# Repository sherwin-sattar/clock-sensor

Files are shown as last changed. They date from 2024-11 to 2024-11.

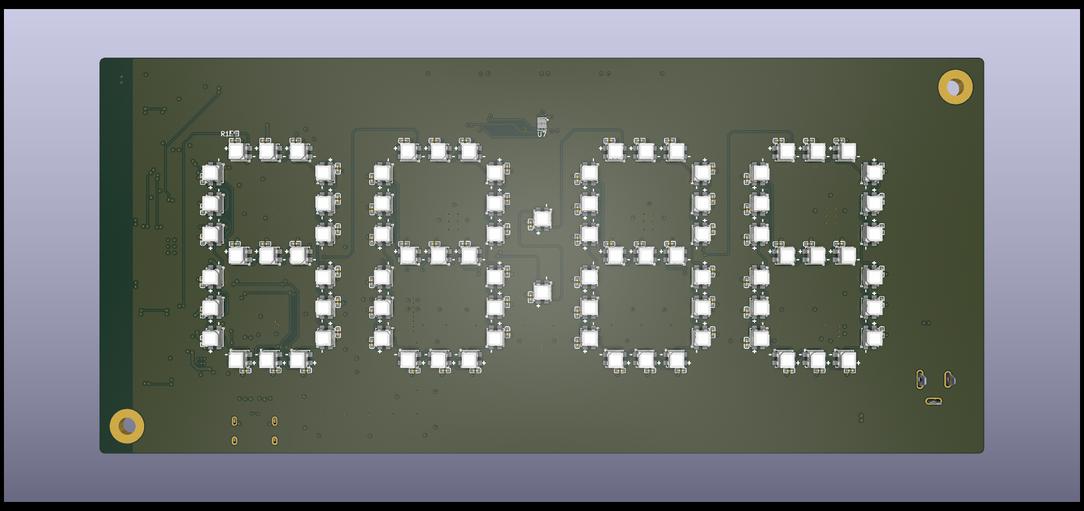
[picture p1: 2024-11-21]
Hardware/3D view/Digital Clock(2).png

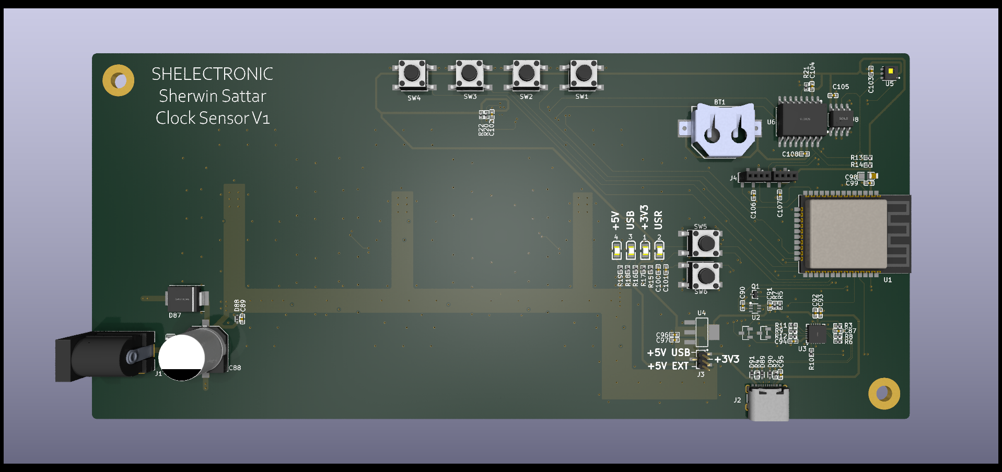
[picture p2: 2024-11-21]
Hardware/3D view/Digital Clock(1).png

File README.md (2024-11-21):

# Clock-Sensor

## User Interface

Web user interface allows seamless control and customization of a clock display, featuring 86 addressable LEDs. Users can adjust and control the clock’s display from anywhere in the world through a secure online connection.
In addition to clock control, the UI also provides real-time monitoring of environmental conditions, including live temperature and humidity readings. Historical data is visualized through easy-to-read graphs, allowing users to track past temperature and humidity trends.

UI-Settings
UI-Data

## 3D views
Digital Clock(2)
Digital Clock(1)

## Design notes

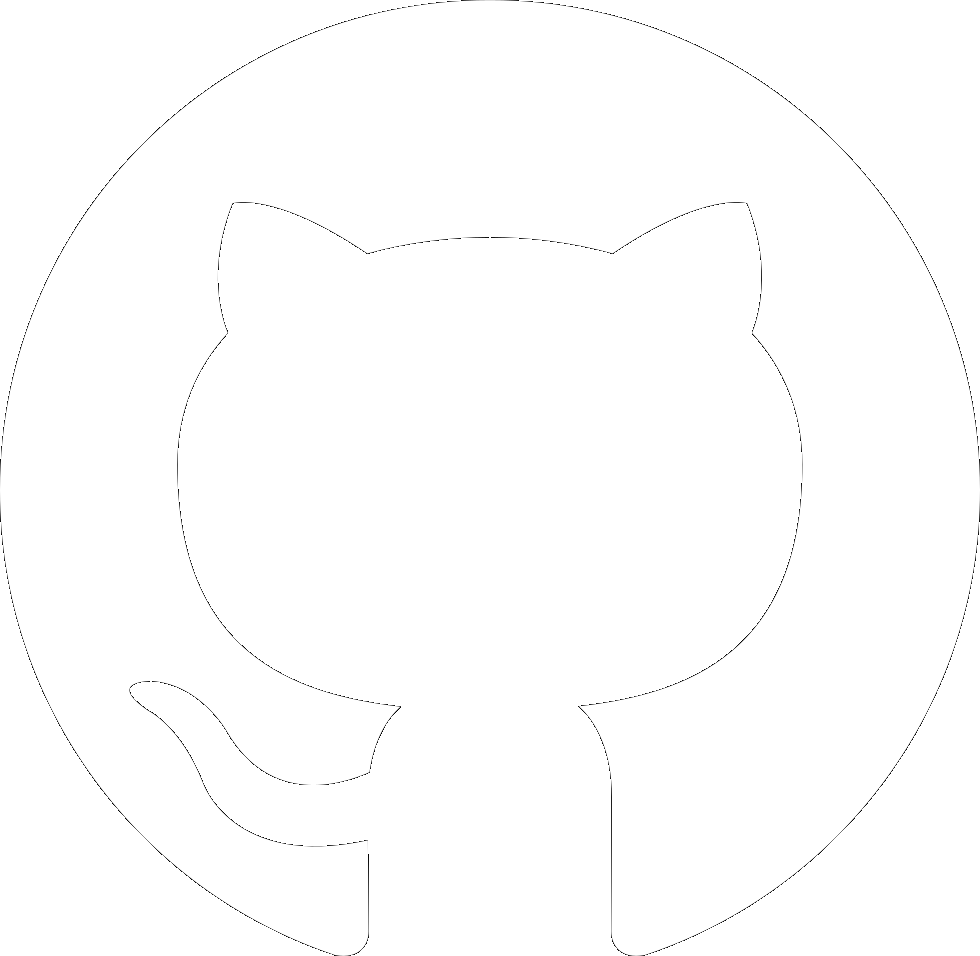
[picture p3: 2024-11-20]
Web_UI/img/git1.png

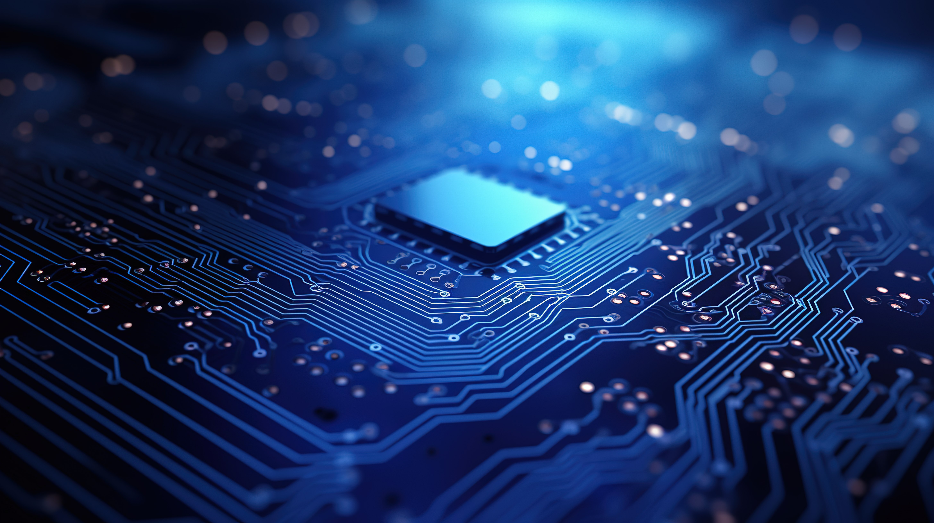
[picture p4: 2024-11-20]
Web_UI/img/home.jpg

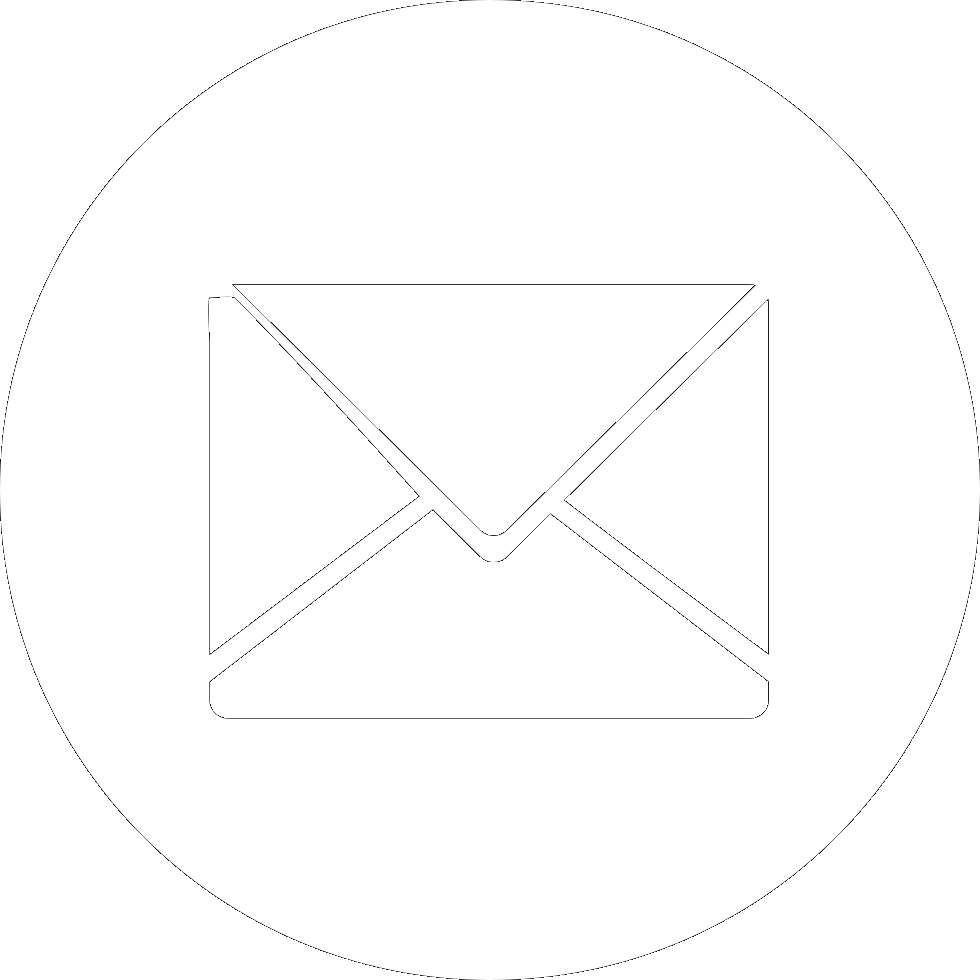
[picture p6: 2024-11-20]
Web_UI/img/mail1.png

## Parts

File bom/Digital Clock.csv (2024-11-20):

Reference | Value | Footprint | LCSC Part | Qty
BT1 | MY-1220-03 | easyeda2kicad:BAT-SMD_MY-1220-03 | C964818 | 1
C1-C87, C89-C91, C93, C94, C99-C108 | 100nF | easyeda2kicad:C0402 | C1525 | 102
C88 | 1000uF | easyeda2kicad:CAP-SMD_BD10.0-L10.3-W10.3-LS11.3-FD | C310843 | 1
C92 | 4.7uF | easyeda2kicad:C0402 | C368809 | 1
C95 | 100n | easyeda2kicad:C0402 | C1525 | 1
C96, C97 | 10uF | easyeda2kicad:C0402 | C315248 | 2
C98 | 22uF | easyeda2kicad:C0805 | C602037 | 1
D1-D86 | WS2812B-MINI | easyeda2kicad:LED-SMD_4P-L3.5-W3.5-TL_WS2812B | C527089 | 86
D87 | SS84 | easyeda2kicad:SMC_L6.9-W5.9-LS7.9-RD | C2943761 | 1
D88 | LESD | easyeda2kicad:SOD-523_L1.2-W0.8-LS1.6-BI | C383211 | 1
D89-D91 | ~ | easyeda2kicad:SOD-523_L1.2-W0.8-LS1.6-BI | C383211 | 3
F1 | SMD1206-600-6V | easyeda2kicad:F1206 | C2760310 | 1
H1, H2 | MountingHole | MountingHole:MountingHole_3.7mm_Pad_TopBottom |  | 2
J1 | DC-005H-D025 | easyeda2kicad:DC-IN-TH_G-SWITCH_DC-005H-D025 | C5353839 | 1
J2 | TYPE-C 16PIN 2MD(073) | easyeda2kicad:USB-C-SMD_TYPE-C-6PIN-2MD-073 | C2765186 | 1
J3 | X1311WVS-03J-C40D42R2 | easyeda2kicad:HDR-SMD_3P-P1.27-V-M-LS4.2_X1311WVS-03J-C40D42R2 | C5243526 | 1
J4, J5 | X1311FVS-04-C43D35R2 | easyeda2kicad:HDR-SMD_4P-P1.27-V-F-LS4.5_R2 | C2881513 | 2
LED1, LED3, LED4 | 0805G (Green) | easyeda2kicad:LED0805-R-RD | C2297 | 3
LED2 | FC-2012HRK (RED) | easyeda2kicad:LED0805-R-RD | C84256 | 1
Q1 | 2N7002T-7-F | easyeda2kicad:SOT-523-3_L1.6-W0.8-P1.00-LS1.6-BR | C139445 | 1
Q2, Q3 | SS8050-G | easyeda2kicad:SOT-23-3_L2.9-W1.3-P1.90-LS2.4-BR | C164886 | 2
R1 | 0402WGF4700TCE | easyeda2kicad:R0402 | C25117 | 1
R2, R4, R16 | 5.1k | easyeda2kicad:R0402 | C25905 | 3
R3, R10, R11, R20, R21 | 0 | easyeda2kicad:R0402 | C17168 | 5
R5 | 1k | easyeda2kicad:R0402 | C11702 | 1
R6, R8 | 27R | easyeda2kicad:R0402 | C138021 | 2
R7, R9, R12, R15, R18, R19, R22 | 10k | easyeda2kicad:R0402 | C25744 | 7
R13, R14 | 2.2k | easyeda2kicad:R0402 | C25879 | 2
R17 | 560 | easyeda2kicad:R0402 | C25126 | 1
SW1-SW6 | PTS645SH50SMTR92LFS | easyeda2kicad:KEY-SMD_4P-L6.0-W6.0-P4.50-LS9.0 | C221869 | 6
U1 | ESP32-WROOM-32E(8MB) | easyeda2kicad:WIFI-SMD_ESP32-WROOM-32E | C701342 | 1
U2 | SN74LVC1T45DCKR | easyeda2kicad:SC-70-6_L2.2-W1.3-P0.65-LS2.2-BR | C9382 | 1
U3 | FT231XQ-R | easyeda2kicad:QFN-20_L4.0-W4.0-P0.50-BL-EP2.2 | C132159 | 1
U4 | AMS1117-3.3_C347222 | easyeda2kicad:SOT-223-4_L6.5-W3.5-P2.30-LS7.0-BR | C347222 | 1
U5 | HDC1080DMBR | easyeda2kicad:SENSOR-SMD_HDC1080DMBR | C82227 | 1
U6 | DS3231SN# | easyeda2kicad:SOIC-16_L10.3-W7.5-P1.27-LS10.3-BL | C9866 | 1
U7 | OPT3001DNPR | easyeda2kicad:USON6_L2.1-W2.1-P0.65-BL-EP | C90462 | 1
U8 | 24LC256T-I/SN SOP-8 | easyeda2kicad:SOIC-8_L4.9-W3.9-P1.27-LS6.0-BL | C5458 | 1

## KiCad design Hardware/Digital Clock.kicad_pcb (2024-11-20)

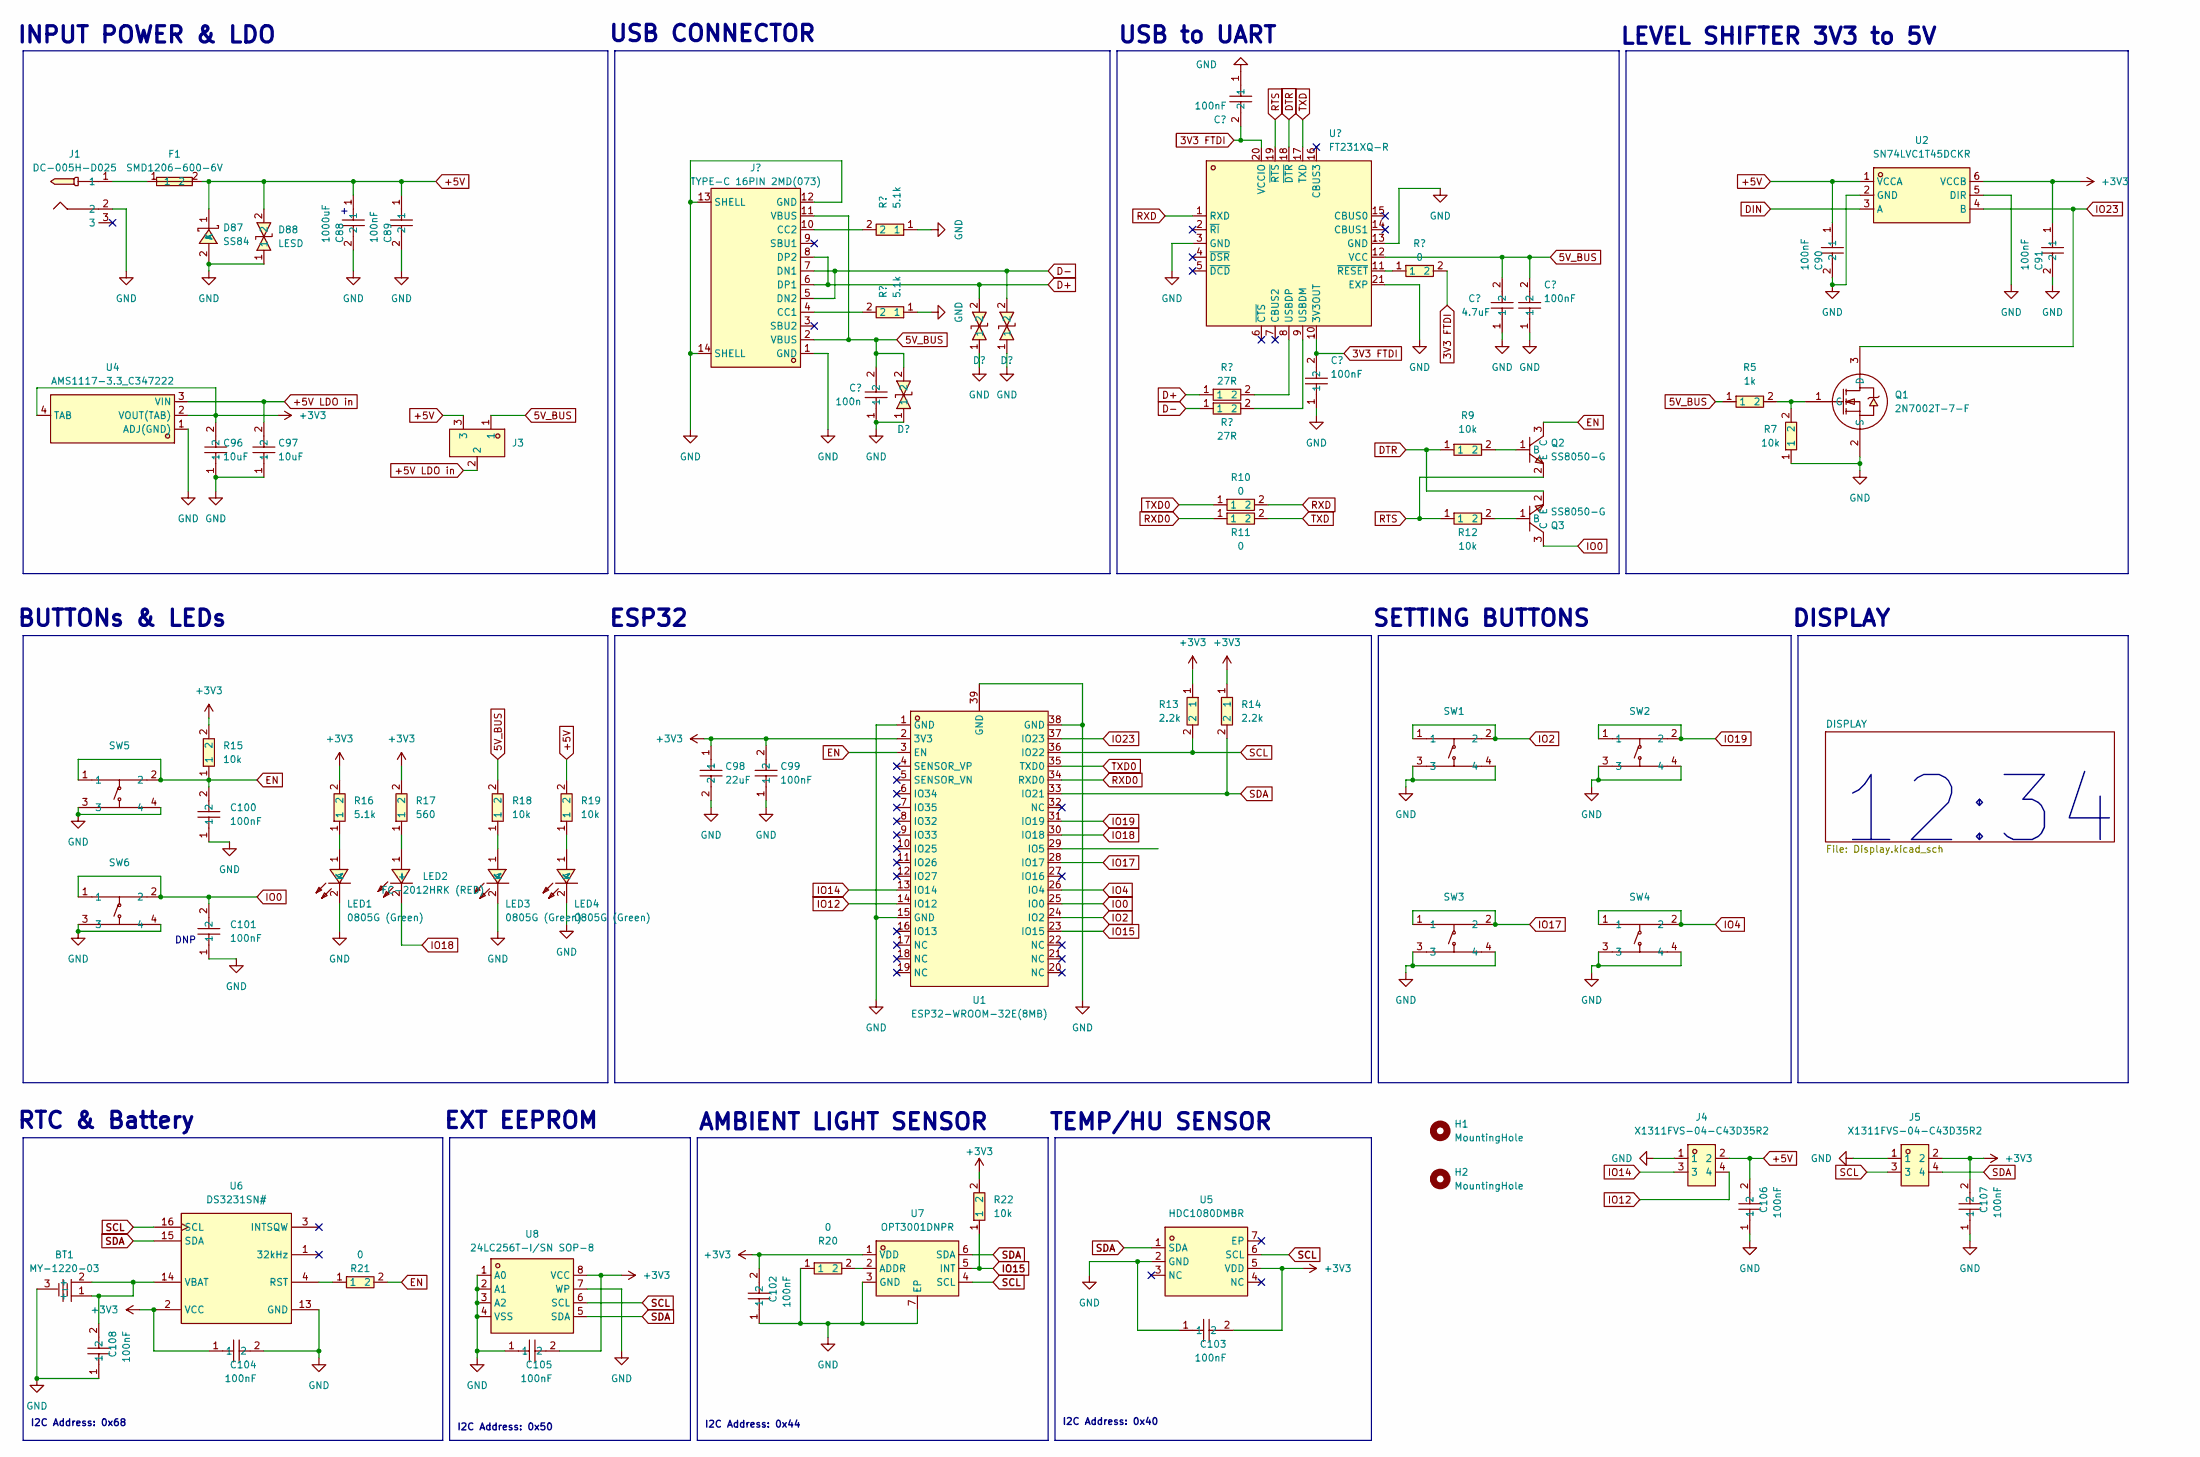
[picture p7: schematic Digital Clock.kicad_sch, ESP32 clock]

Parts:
BT1: MY-1220-03; BAT-SMD_MY-1220-03; LCSC Part C964818
C87, C89, C90, C91, C93, C94, C99, C100, C101, C102, C103, C104, C105, C106, C107, C108: 100nF; C0402; LCSC Part C1525
C88: 1000uF; CAP-SMD_BD10.0-L10.3-W10.3-LS11.3-FD; LCSC Part C310843
C92: 4.7uF; C0402; LCSC Part C368809
C95: 100n; C0402; LCSC Part C1525
C96, C97: 10uF; C0402; LCSC Part C315248
C98: 22uF; C0805; LCSC Part C602037
D87: SS84; SMC_L6.9-W5.9-LS7.9-RD; LCSC Part C2943761
D88: LESD; SOD-523_L1.2-W0.8-LS1.6-BI; LCSC Part C383211
D89, D90, D91: SOD-523_L1.2-W0.8-LS1.6-BI; LCSC Part C383211
F1: SMD1206-600-6V; F1206; LCSC Part C2760310
H1, H2: MountingHole; MountingHole_3.7mm_Pad_TopBottom
J1: DC-005H-D025; DC-IN-TH_G-SWITCH_DC-005H-D025; LCSC Part C5353839
J2: TYPE-C 16PIN 2MD(073); USB-C-SMD_TYPE-C-6PIN-2MD-073; LCSC Part C2765186
J3: X1311WVS-03J-C40D42R2; HDR-SMD_3P-P1.27-V-M-LS4.2_X1311WVS-03J-C40D42R2; LCSC Part C5243526
J4, J5: X1311FVS-04-C43D35R2; HDR-SMD_4P-P1.27-V-F-LS4.5_R2; LCSC Part C2881513
LED1, LED3, LED4: 0805G (Green); LED0805-R-RD; LCSC Part C2297
LED2: FC-2012HRK (RED); LED0805-R-RD; LCSC Part C84256
Q1: 2N7002T-7-F; SOT-523-3_L1.6-W0.8-P1.00-LS1.6-BR; LCSC Part C139445
Q2, Q3: SS8050-G; SOT-23-3_L2.9-W1.3-P1.90-LS2.4-BR; LCSC Part C164886
R2, R4, R16: 5.1k; R0402; LCSC Part C25905
R3, R10, R11, R20, R21: 0; R0402; LCSC Part C17168
R5: 1k; R0402; LCSC Part C11702
R6, R8: 27R; R0402; LCSC Part C138021
R7, R9, R12, R15, R18, R19, R22: 10k; R0402; LCSC Part C25744
R13, R14: 2.2k; R0402; LCSC Part C25879
R17: 560; R0402; LCSC Part C25126
SW1, SW2, SW3, SW4, SW5, SW6: PTS645SH50SMTR92LFS; KEY-SMD_4P-L6.0-W6.0-P4.50-LS9.0; LCSC Part C221869
U1: ESP32-WROOM-32E(8MB); WIFI-SMD_ESP32-WROOM-32E; LCSC Part C701342
U2: SN74LVC1T45DCKR; SC-70-6_L2.2-W1.3-P0.65-LS2.2-BR; LCSC Part C9382
U3: FT231XQ-R; QFN-20_L4.0-W4.0-P0.50-BL-EP2.2; LCSC Part C132159
U4: AMS1117-3.3_C347222; SOT-223-4_L6.5-W3.5-P2.30-LS7.0-BR; LCSC Part C347222
U5: HDC1080DMBR; SENSOR-SMD_HDC1080DMBR; LCSC Part C82227
U6: DS3231SN#; SOIC-16_L10.3-W7.5-P1.27-LS10.3-BL; LCSC Part C9866
U7: OPT3001DNPR; USON6_L2.1-W2.1-P0.65-BL-EP; LCSC Part C90462
U8: 24LC256T-I/SN SOP-8; SOIC-8_L4.9-W3.9-P1.27-LS6.0-BL; LCSC Part C5458

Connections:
3V3 FTDI: C87.2, C94.2, R3.2, U3.10 (3V3OUT), U3.20 (VCCIO)
5V_BUS: C92.2, C93.2, C95.2, D91.2, J2.2 (VBUS), J2.11 (VBUS), J3.1, R5.1, R18.2, U3.12 (VCC)
+3V3: C91.1, C96.2, C98.1, C99.2, C102.2, C103.2, C104.1, C105.2, C107.2, J5.2, R13.1, R14.1, R15.2, R16.2, R17.2, R22.2, U1.2 (3V3), U2.6 (VCCB), U4.2 (VOUT(TAB)), U4.4 (TAB), U5.5 (VDD), U6.2 (VCC), U7.1 (VDD), U8.8 (VCC)
+5V: C88.1, C89.1, C90.1, C106.2, D87.1 (K), D88.2, F1.2, J3.3, J4.2, R19.2, U2.1 (VCCA); also elsewhere on the board
+5V LDO in: C97.2, J3.2, U4.3 (VIN)
D+: D89.2, J2.6 (DP1), J2.8 (DP2), R6.1
D-: D90.2, J2.5 (DN2), J2.7 (DN1), R8.1
DIN: U2.3 (A); also elsewhere on the board
DTR: Q3.2 (E), R9.1, U3.18 (~DTR)
EN: C100.2, Q2.3 (C), R15.1, R21.2, SW5.1, SW5.2, U1.3 (EN)
GND: BT1.3 (-), C87.1, C88.2, C89.2, C90.2, C91.2, C92.1, C93.1, C94.1, C95.1, C96.1, C97.1, C98.2, C99.1, C100.1, C101.1, C102.1, C103.1, C104.2, C105.1, C106.1, C107.1, C108.1, D87.2 (A), D88.1, D89.1, D90.1, D91.1, J1.2, J2.1 (GND), J2.12 (GND), J2.13 (SHELL), J2.14 (SHELL), J4.1, J5.1, LED1.2 (K), LED3.2 (K), LED4.2 (K), Q1.2 (S), R2.1, R4.1, R7.1, R20.1, SW1.3, SW1.4, SW2.3, SW2.4, SW3.3, SW3.4, SW4.3, SW4.4, SW5.3, SW5.4, SW6.3, SW6.4, U1.1 (GND), U1.15 (GND), U1.38 (GND), U1.39 (GND), U2.2 (GND), U2.5 (DIR), U3.3 (GND), U3.13 (GND), U3.21 (EXP), U4.1 (ADJ(GND)), U5.2 (GND), U6.13 (GND), U7.3 (GND), U7.7 (EP), U8.1 (A0), U8.2 (A1), U8.3 (A2), U8.4 (VSS), U8.7 (WP); also elsewhere on the board
IO0: C101.2, Q3.3 (C), SW6.1, SW6.2, U1.25 (IO0)
IO2: SW1.1, SW1.2, U1.24 (IO2)
IO4: SW4.1, SW4.2, U1.26 (IO4)
IO12: J4.4, U1.14 (IO12)
IO14: J4.3, U1.13 (IO14)
IO15: R22.1, U1.23 (IO15), U7.5 (INT)
IO17: SW3.1, SW3.2, U1.28 (IO17)
IO18: LED2.2 (-), U1.30 (IO18); also elsewhere on the board
IO19: SW2.1, SW2.2, U1.31 (IO19)
IO23: Q1.3 (D), U1.37 (IO23), U2.4 (B)
unnamed: F1.1, J1.1
unnamed: J2.4 (CC1), R4.2
unnamed: J2.10 (CC2), R2.2
unnamed 102: LED1.1 (A), R16.1; also elsewhere on the board
unnamed 103: LED2.1 (+), R17.1; also elsewhere on the board
unnamed 104: LED3.1 (A), R18.1; also elsewhere on the board
unnamed 105: LED4.1 (A), R19.1; also elsewhere on the board
unnamed: Q1.1 (G), R5.2, R7.2
unnamed: Q2.1 (B), R9.2
unnamed: Q3.1 (B), R12.2
unnamed: R8.2, U3.9 (USBDM)
unnamed: R6.2, U3.8 (USBDP)
unnamed: R3.1, U3.11 (~RESET)
unnamed: R21.1, U6.4 (RST)
unnamed: BT1.1 (+), BT1.2 (+), C108.2, U6.14 (VBAT)
unnamed: R20.2, U7.2 (ADDR)
RTS: Q2.2 (E), R12.1, U3.19 (~RTS)
RXD: R10.2, U3.1 (RXD)
RXD0: R11.1, U1.34 (RXD0)
SCL: J5.3, R13.2, U1.36 (IO22), U5.6 (SCL), U6.16 (SCL), U7.4 (SCL), U8.6 (SCL)
SDA: J5.4, R14.2, U1.33 (IO21), U5.1 (SDA), U6.15 (SDA), U7.6 (SDA), U8.5 (SDA)
TXD: R11.2, U3.17 (TXD)
TXD0: R10.1, U1.35 (TXD0)

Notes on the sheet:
I2C Address: 0x44
INPUT POWER & LDO
USB CONNECTOR
BUTTONs & LEDs
USB to UART
ESP32
RTC & Battery
I2C Address: 0x68
EXT EEPROM
AMBIENT LIGHT SENSOR
I2C Address: 0x50
I2C Address: 0x40
DNP
TEMP/HU SENSOR
12:34
LEVEL SHIFTER 3V3 to 5V
SETTING BUTTONS
DISPLAY

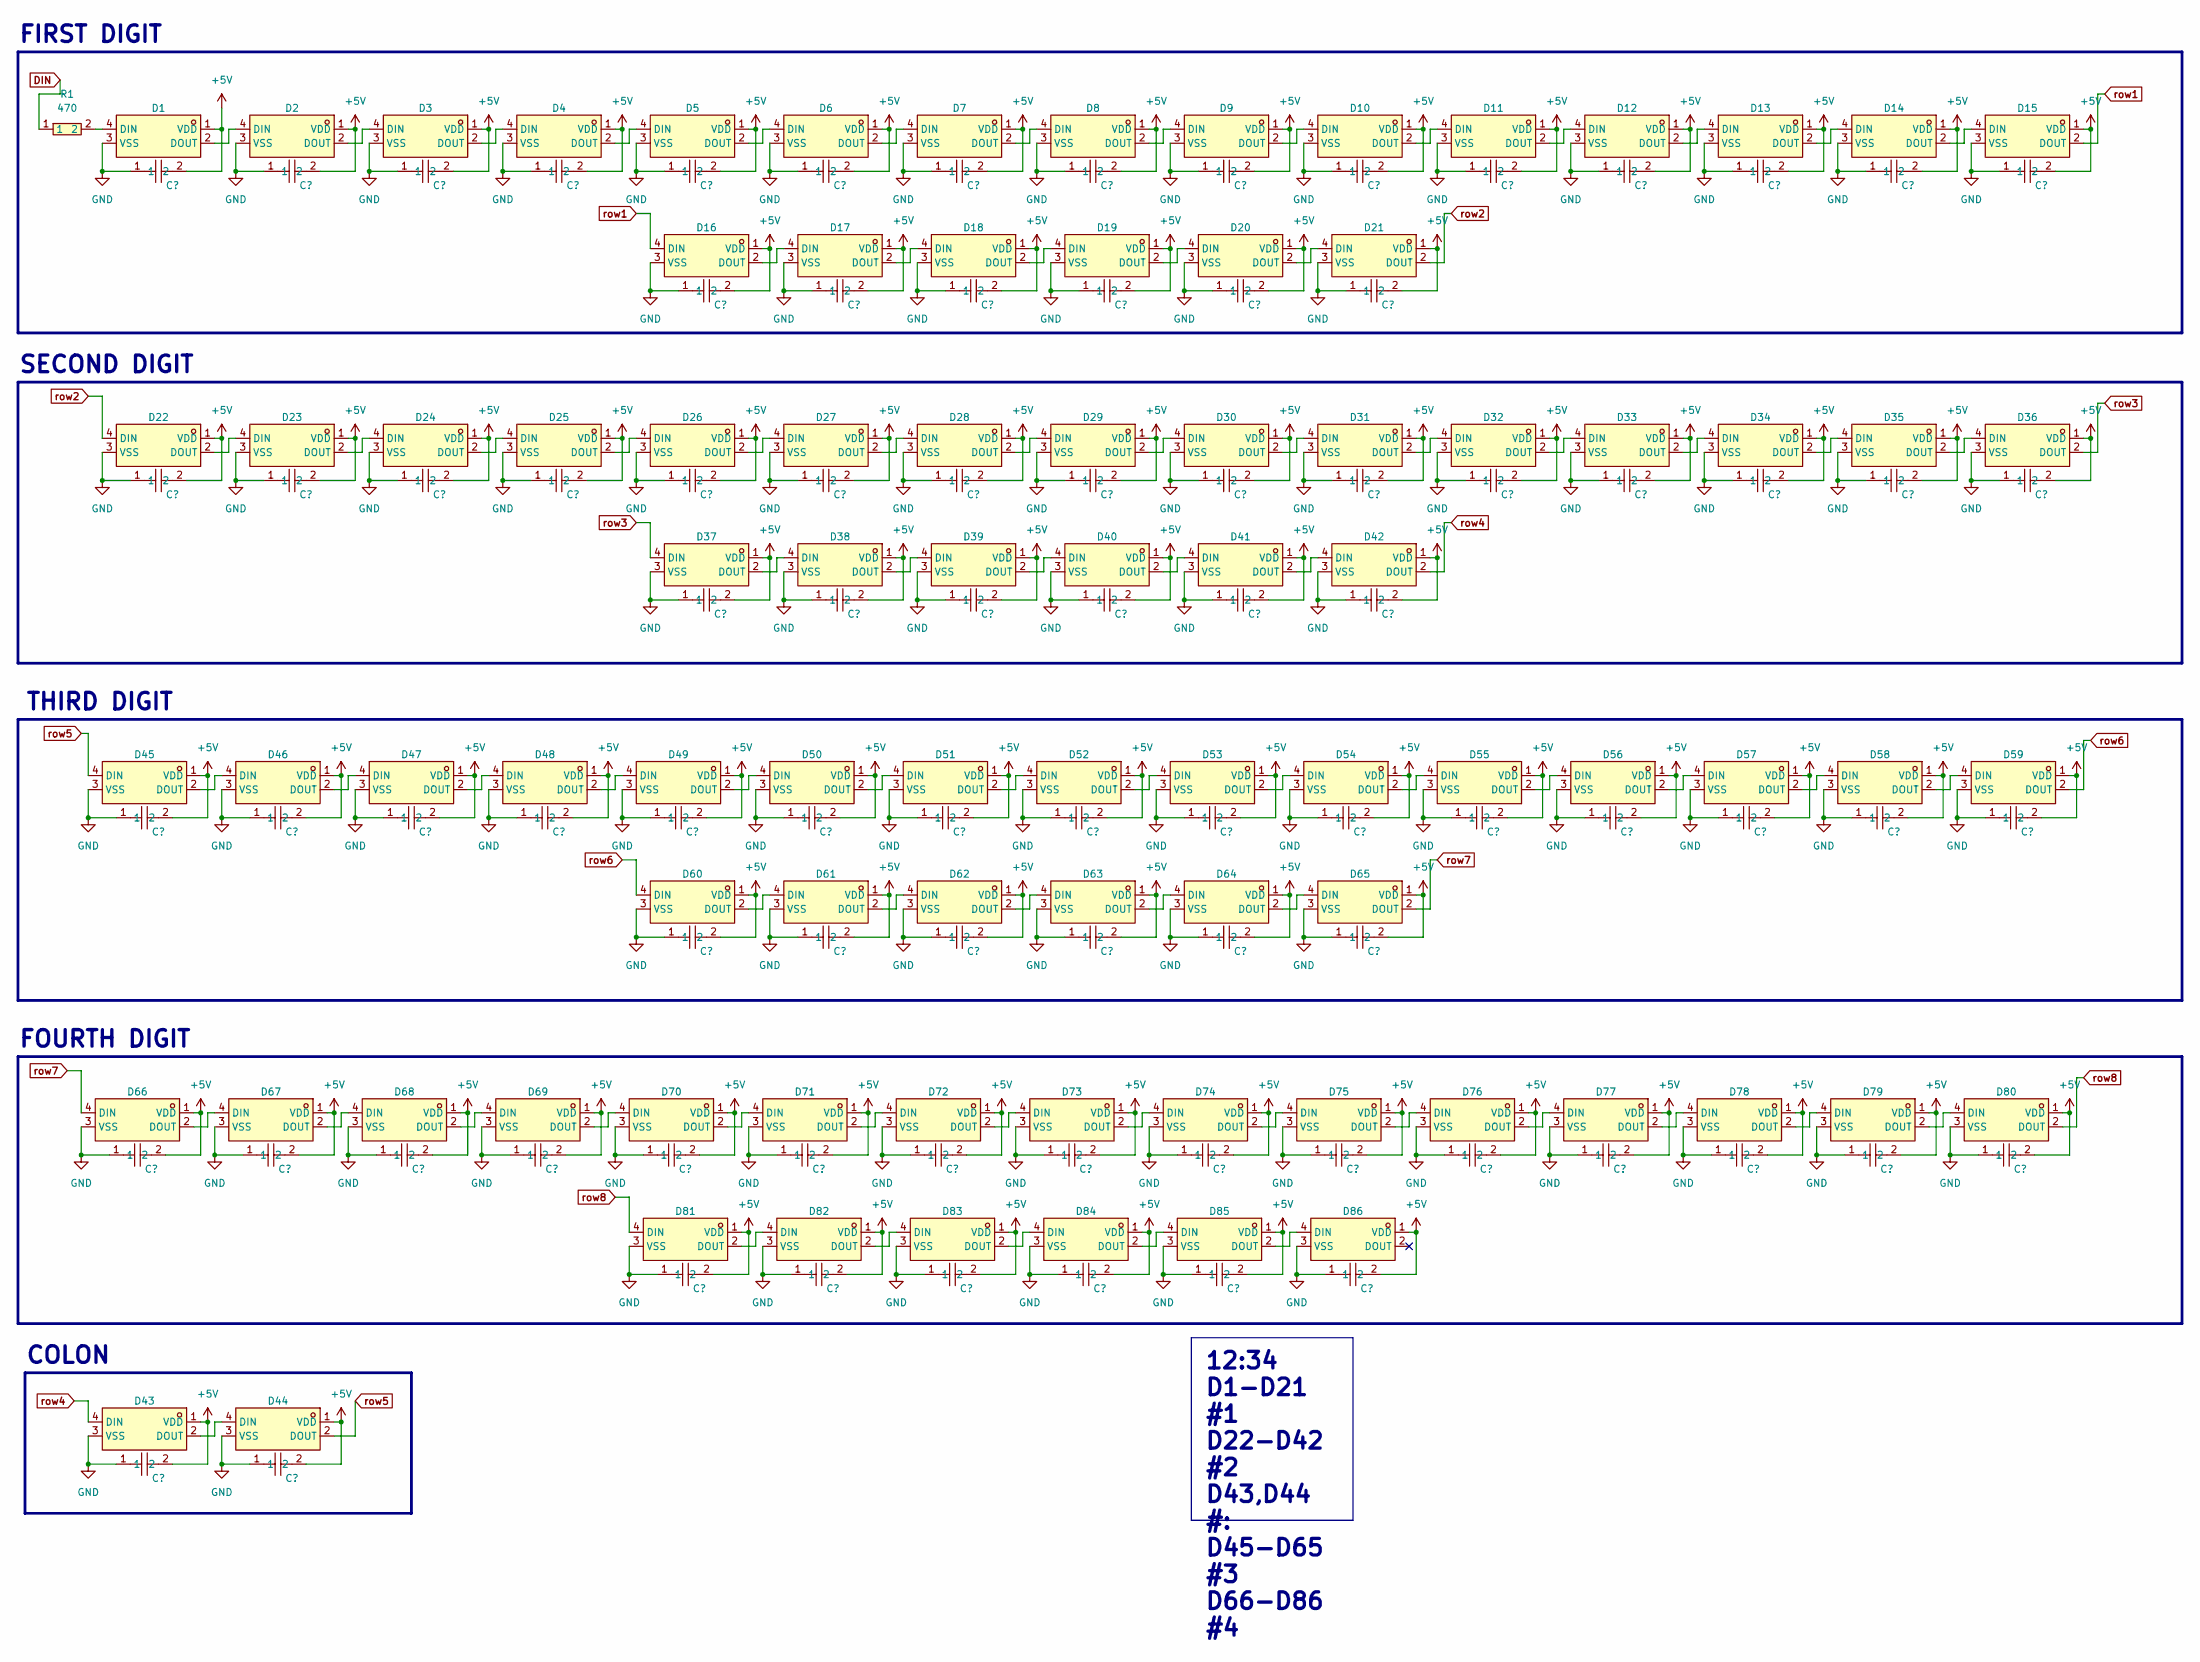
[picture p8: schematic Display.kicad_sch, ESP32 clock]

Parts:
C1, C2, C3, C4, C5, C6, C7, C8, C9, C10, C11, C12, C13, C14, C15, C16, C17, C18, C19, C20, C21, C22, C23, C24, C25, C26, C27, C28, C29, C30, C31, C32, C33, C34, C35, C36, C37, C38, C39, C40, C41, C42, C43, C44, C45, C46, C47, C48, C49, C50, C51, C52, C53, C54, C55, C56, C57, C58, C59, C60, C61, C62, C63, C64, C65, C66, C67, C68, C69, C70, C71, C72, C73, C74, C75, C76, C77, C78, C79, C80, C81, C82, C83, C84, C85, C86: 100nF; C0402; LCSC Part C1525
D1, D2, D3, D4, D5, D6, D7, D8, D9, D10, D11, D12, D13, D14, D15, D16, D17, D18, D19, D20, D21, D22, D23, D24, D25, D26, D27, D28, D29, D30, D31, D32, D33, D34, D35, D36, D37, D38, D39, D40, D41, D42, D43, D44, D45, D46, D47, D48, D49, D50, D51, D52, D53, D54, D55, D56, D57, D58, D59, D60, D61, D62, D63, D64, D65, D66, D67, D68, D69, D70, D71, D72, D73, D74, D75, D76, D77, D78, D79, D80, D81, D82, D83, D84, D85, D86: WS2812B-MINI; LED-SMD_4P-L3.5-W3.5-TL_WS2812B; LCSC Part C527089
R1: 470; R0402; LCSC Part C25117

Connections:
+5V: C1.2, C2.2, C3.2, C4.2, C5.2, C6.2, C7.2, C8.2, C9.2, C10.2, C11.2, C12.2, C13.2, C14.2, C15.2, C16.2, C17.2, C18.2, C19.2, C20.2, C21.2, C22.2, C23.2, C24.2, C25.2, C26.2, C27.2, C28.2, C29.2, C30.2, C31.2, C32.2, C33.2, C34.2, C35.2, C36.2, C37.2, C38.2, C39.2, C40.2, C41.2, C42.2, C43.2, C44.2, C45.2, C46.2, C47.2, C48.2, C49.2, C50.2, C51.2, C52.2, C53.2, C54.2, C55.2, C56.2, C57.2, C58.2, C59.2, C60.2, C61.2, C62.2, C63.2, C64.2, C65.2, C66.2, C67.2, C68.2, C69.2, C70.2, C71.2, C72.2, C73.2, C74.2, C75.2, C76.2, C77.2, C78.2, C79.2, C80.2, C81.2, C82.2, C83.2, C84.2, C85.2, C86.2, D1.1 (VDD), D2.1 (VDD), D3.1 (VDD), D4.1 (VDD), D5.1 (VDD), D6.1 (VDD), D7.1 (VDD), D8.1 (VDD), D9.1 (VDD), D10.1 (VDD), D11.1 (VDD), D12.1 (VDD), D13.1 (VDD), D14.1 (VDD), D15.1 (VDD), D16.1 (VDD), D17.1 (VDD), D18.1 (VDD), D19.1 (VDD), D20.1 (VDD), D21.1 (VDD), D22.1 (VDD), D23.1 (VDD), D24.1 (VDD), D25.1 (VDD), D26.1 (VDD), D27.1 (VDD), D28.1 (VDD), D29.1 (VDD), D30.1 (VDD), D31.1 (VDD), D32.1 (VDD), D33.1 (VDD), D34.1 (VDD), D35.1 (VDD), D36.1 (VDD), D37.1 (VDD), D38.1 (VDD), D39.1 (VDD), D40.1 (VDD), D41.1 (VDD), D42.1 (VDD), D43.1 (VDD), D44.1 (VDD), D45.1 (VDD), D46.1 (VDD), D47.1 (VDD), D48.1 (VDD), D49.1 (VDD), D50.1 (VDD), D51.1 (VDD), D52.1 (VDD), D53.1 (VDD), D54.1 (VDD), D55.1 (VDD), D56.1 (VDD), D57.1 (VDD), D58.1 (VDD), D59.1 (VDD), D60.1 (VDD), D61.1 (VDD), D62.1 (VDD), D63.1 (VDD), D64.1 (VDD), D65.1 (VDD), D66.1 (VDD), D67.1 (VDD), D68.1 (VDD), D69.1 (VDD), D70.1 (VDD), D71.1 (VDD), D72.1 (VDD), D73.1 (VDD), D74.1 (VDD), D75.1 (VDD), D76.1 (VDD), D77.1 (VDD), D78.1 (VDD), D79.1 (VDD), D80.1 (VDD), D81.1 (VDD), D82.1 (VDD), D83.1 (VDD), D84.1 (VDD), D85.1 (VDD), D86.1 (VDD); also elsewhere on the board
DIN: R1.1; also elsewhere on the board
GND: C1.1, C2.1, C3.1, C4.1, C5.1, C6.1, C7.1, C8.1, C9.1, C10.1, C11.1, C12.1, C13.1, C14.1, C15.1, C16.1, C17.1, C18.1, C19.1, C20.1, C21.1, C22.1, C23.1, C24.1, C25.1, C26.1, C27.1, C28.1, C29.1, C30.1, C31.1, C32.1, C33.1, C34.1, C35.1, C36.1, C37.1, C38.1, C39.1, C40.1, C41.1, C42.1, C43.1, C44.1, C45.1, C46.1, C47.1, C48.1, C49.1, C50.1, C51.1, C52.1, C53.1, C54.1, C55.1, C56.1, C57.1, C58.1, C59.1, C60.1, C61.1, C62.1, C63.1, C64.1, C65.1, C66.1, C67.1, C68.1, C69.1, C70.1, C71.1, C72.1, C73.1, C74.1, C75.1, C76.1, C77.1, C78.1, C79.1, C80.1, C81.1, C82.1, C83.1, C84.1, C85.1, C86.1, D1.3 (VSS), D2.3 (VSS), D3.3 (VSS), D4.3 (VSS), D5.3 (VSS), D6.3 (VSS), D7.3 (VSS), D8.3 (VSS), D9.3 (VSS), D10.3 (VSS), D11.3 (VSS), D12.3 (VSS), D13.3 (VSS), D14.3 (VSS), D15.3 (VSS), D16.3 (VSS), D17.3 (VSS), D18.3 (VSS), D19.3 (VSS), D20.3 (VSS), D21.3 (VSS), D22.3 (VSS), D23.3 (VSS), D24.3 (VSS), D25.3 (VSS), D26.3 (VSS), D27.3 (VSS), D28.3 (VSS), D29.3 (VSS), D30.3 (VSS), D31.3 (VSS), D32.3 (VSS), D33.3 (VSS), D34.3 (VSS), D35.3 (VSS), D36.3 (VSS), D37.3 (VSS), D38.3 (VSS), D39.3 (VSS), D40.3 (VSS), D41.3 (VSS), D42.3 (VSS), D43.3 (VSS), D44.3 (VSS), D45.3 (VSS), D46.3 (VSS), D47.3 (VSS), D48.3 (VSS), D49.3 (VSS), D50.3 (VSS), D51.3 (VSS), D52.3 (VSS), D53.3 (VSS), D54.3 (VSS), D55.3 (VSS), D56.3 (VSS), D57.3 (VSS), D58.3 (VSS), D59.3 (VSS), D60.3 (VSS), D61.3 (VSS), D62.3 (VSS), D63.3 (VSS), D64.3 (VSS), D65.3 (VSS), D66.3 (VSS), D67.3 (VSS), D68.3 (VSS), D69.3 (VSS), D70.3 (VSS), D71.3 (VSS), D72.3 (VSS), D73.3 (VSS), D74.3 (VSS), D75.3 (VSS), D76.3 (VSS), D77.3 (VSS), D78.3 (VSS), D79.3 (VSS), D80.3 (VSS), D81.3 (VSS), D82.3 (VSS), D83.3 (VSS), D84.3 (VSS), D85.3 (VSS), D86.3 (VSS); also elsewhere on the board
unnamed: D1.4 (DIN), R1.2
unnamed: D1.2 (DOUT), D2.4 (DIN)
unnamed: D2.2 (DOUT), D3.4 (DIN)
unnamed: D3.2 (DOUT), D4.4 (DIN)
unnamed: D4.2 (DOUT), D5.4 (DIN)
unnamed: D5.2 (DOUT), D6.4 (DIN)
unnamed: D6.2 (DOUT), D7.4 (DIN)
unnamed: D7.2 (DOUT), D8.4 (DIN)
unnamed: D8.2 (DOUT), D9.4 (DIN)
unnamed: D9.2 (DOUT), D10.4 (DIN)
unnamed: D10.2 (DOUT), D11.4 (DIN)
unnamed: D11.2 (DOUT), D12.4 (DIN)
unnamed: D12.2 (DOUT), D13.4 (DIN)
unnamed: D13.2 (DOUT), D14.4 (DIN)
unnamed: D14.2 (DOUT), D15.4 (DIN)
unnamed: D16.2 (DOUT), D17.4 (DIN)
unnamed: D17.2 (DOUT), D18.4 (DIN)
unnamed: D18.2 (DOUT), D19.4 (DIN)
unnamed: D19.2 (DOUT), D20.4 (DIN)
unnamed: D20.2 (DOUT), D21.4 (DIN)
unnamed: D22.2 (DOUT), D23.4 (DIN)
unnamed: D23.2 (DOUT), D24.4 (DIN)
unnamed: D24.2 (DOUT), D25.4 (DIN)
unnamed: D25.2 (DOUT), D26.4 (DIN)
unnamed: D26.2 (DOUT), D27.4 (DIN)
unnamed: D27.2 (DOUT), D28.4 (DIN)
unnamed: D28.2 (DOUT), D29.4 (DIN)
unnamed: D29.2 (DOUT), D30.4 (DIN)
unnamed: D30.2 (DOUT), D31.4 (DIN)
unnamed: D31.2 (DOUT), D32.4 (DIN)
unnamed: D32.2 (DOUT), D33.4 (DIN)
unnamed: D33.2 (DOUT), D34.4 (DIN)
unnamed: D34.2 (DOUT), D35.4 (DIN)
unnamed: D35.2 (DOUT), D36.4 (DIN)
unnamed: D37.2 (DOUT), D38.4 (DIN)
unnamed: D38.2 (DOUT), D39.4 (DIN)
unnamed: D39.2 (DOUT), D40.4 (DIN)
unnamed: D40.2 (DOUT), D41.4 (DIN)
unnamed: D41.2 (DOUT), D42.4 (DIN)
unnamed: D43.2 (DOUT), D44.4 (DIN)
unnamed: D45.2 (DOUT), D46.4 (DIN)
unnamed: D46.2 (DOUT), D47.4 (DIN)
unnamed: D47.2 (DOUT), D48.4 (DIN)
unnamed: D48.2 (DOUT), D49.4 (DIN)
unnamed: D49.2 (DOUT), D50.4 (DIN)
unnamed: D50.2 (DOUT), D51.4 (DIN)
unnamed: D51.2 (DOUT), D52.4 (DIN)
unnamed: D52.2 (DOUT), D53.4 (DIN)
unnamed: D53.2 (DOUT), D54.4 (DIN)
unnamed: D54.2 (DOUT), D55.4 (DIN)
unnamed: D55.2 (DOUT), D56.4 (DIN)
unnamed: D56.2 (DOUT), D57.4 (DIN)
unnamed: D57.2 (DOUT), D58.4 (DIN)
unnamed: D58.2 (DOUT), D59.4 (DIN)
unnamed: D60.2 (DOUT), D61.4 (DIN)
unnamed: D61.2 (DOUT), D62.4 (DIN)
unnamed: D62.2 (DOUT), D63.4 (DIN)
unnamed: D63.2 (DOUT), D64.4 (DIN)
unnamed: D64.2 (DOUT), D65.4 (DIN)
unnamed: D66.2 (DOUT), D67.4 (DIN)
unnamed: D67.2 (DOUT), D68.4 (DIN)
unnamed: D68.2 (DOUT), D69.4 (DIN)
unnamed: D69.2 (DOUT), D70.4 (DIN)
unnamed: D70.2 (DOUT), D71.4 (DIN)
unnamed: D71.2 (DOUT), D72.4 (DIN)
unnamed: D72.2 (DOUT), D73.4 (DIN)
unnamed: D73.2 (DOUT), D74.4 (DIN)
unnamed: D74.2 (DOUT), D75.4 (DIN)
unnamed: D75.2 (DOUT), D76.4 (DIN)
unnamed: D76.2 (DOUT), D77.4 (DIN)
unnamed: D77.2 (DOUT), D78.4 (DIN)
unnamed: D78.2 (DOUT), D79.4 (DIN)
unnamed: D79.2 (DOUT), D80.4 (DIN)
unnamed: D81.2 (DOUT), D82.4 (DIN)
unnamed: D82.2 (DOUT), D83.4 (DIN)
unnamed: D83.2 (DOUT), D84.4 (DIN)
unnamed: D84.2 (DOUT), D85.4 (DIN)
unnamed: D85.2 (DOUT), D86.4 (DIN)
row1: D15.2 (DOUT), D16.4 (DIN)
row2: D21.2 (DOUT), D22.4 (DIN)
row3: D36.2 (DOUT), D37.4 (DIN)
row4: D42.2 (DOUT), D43.4 (DIN)
row5: D44.2 (DOUT), D45.4 (DIN)
row6: D59.2 (DOUT), D60.4 (DIN)
row7: D65.2 (DOUT), D66.4 (DIN)
row8: D80.2 (DOUT), D81.4 (DIN)

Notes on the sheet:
12:34 D1-D21 #1 D22-D42 #2 D43,D44 #: D45-D65 #3 D66-D86 #4
FOURTH DIGIT
SECOND DIGIT
COLON
FIRST DIGIT
THIRD DIGIT

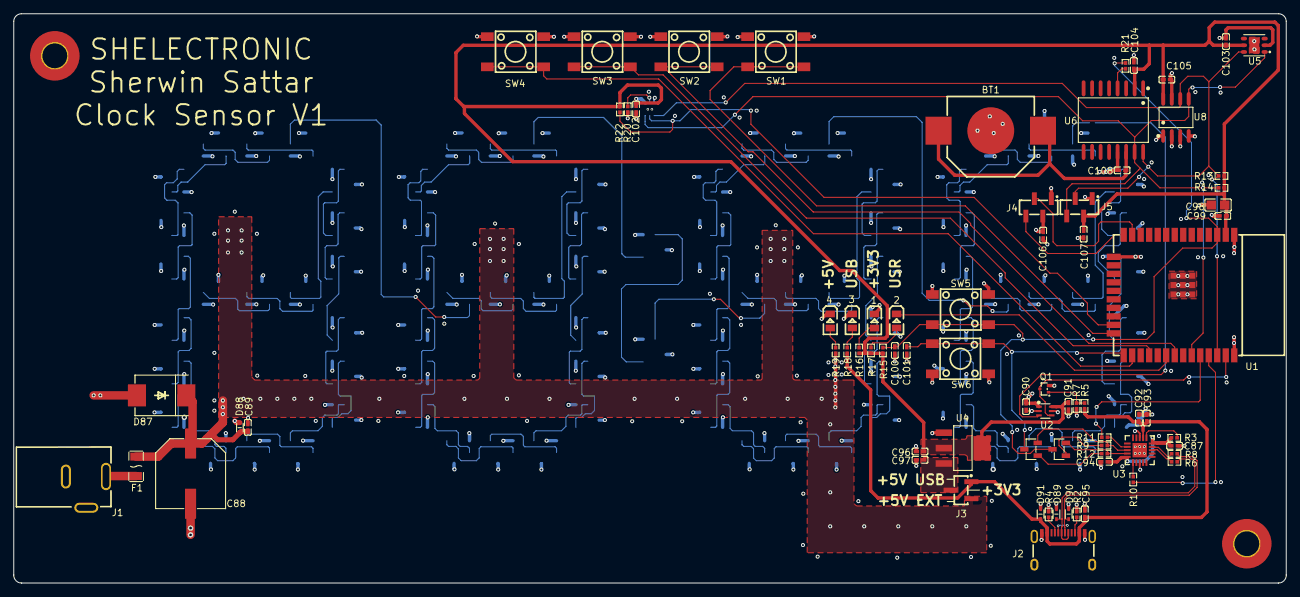
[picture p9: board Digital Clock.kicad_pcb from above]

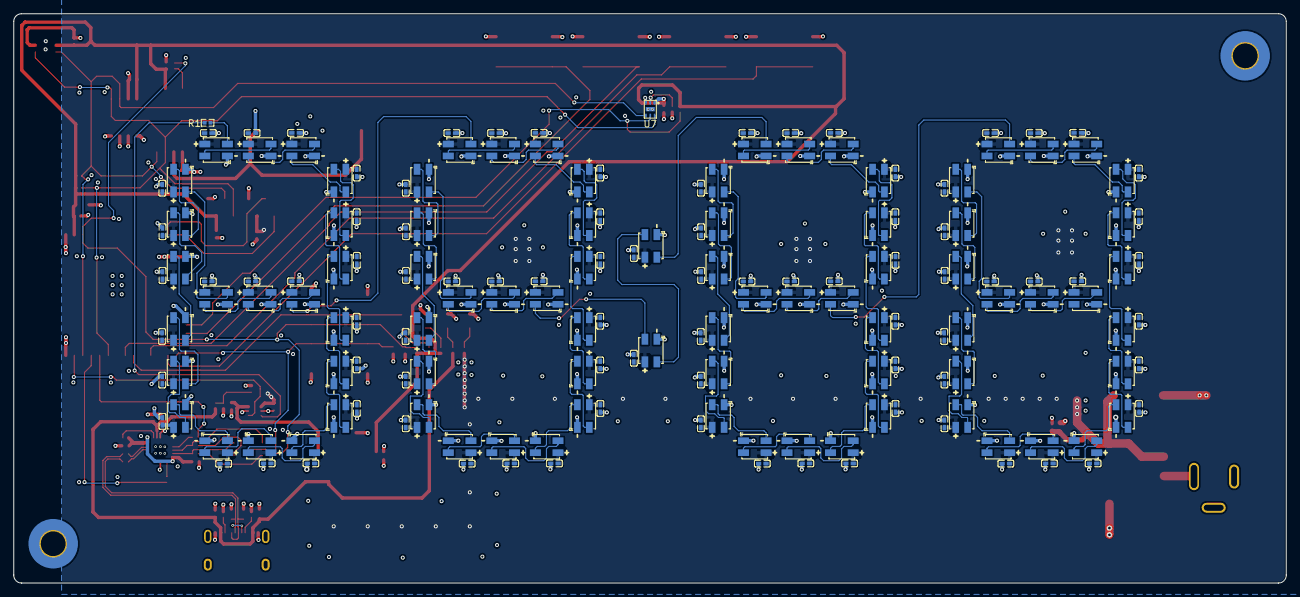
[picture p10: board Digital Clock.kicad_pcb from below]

Board: 4 copper layers, 190.0 x 85.0 mm, 251 parts (174 on the bottom side), 130 nets.

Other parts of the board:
1, 3, 4: 0805G (Green); LED0805-R-RD
2: FC-2012HRK (RED); LED0805-R-RD

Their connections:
GND: 1.2 (K), 3.2 (K), 4.2 (K); also elsewhere on the board
IO18: 2.2 (-); also elsewhere on the board
unnamed 102: 1.1 (A); also elsewhere on the board
unnamed 103: 2.1 (+); also elsewhere on the board
unnamed 104: 3.1 (A); also elsewhere on the board
unnamed 105: 4.1 (A); also elsewhere on the board

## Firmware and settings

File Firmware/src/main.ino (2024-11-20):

#include "Display.h"
#include "Sensor.h"
#include <HTTPClient.h>
#include <Wire.h>
#include <RTClib.h>
#include <WiFi.h>
#include <NTPClient.h>
#include <HTTPClient.h>
#include <WiFiUdp.h>
#include <NeoPixelBus.h>
#include <ClosedCube_OPT3001.h>
#include "ClosedCube_HDC1080.h"
#include <Preferences.h>

#define OPT3001_ADDRESS 0x44                       // Ambient sensor address
#define hdc1080_ADDRESS 0x40                       // temp sensoe address
const char* serverUrl = "***";                     // Replace with domain address
const char *ssid = "***";                          // WiFi SSID
const char *password = "***";                      // WiFi Password
const uint16_t PixelCount = 86;                    // Total number of LEDs
const uint8_t PixelPin = 23;                       // Display Din
const int button1 = 2;                             // GPIO2 for SW1
const int button2 = 19;                            // GPIO2 for SW2
const int button3 = 17; 
int lastButton1State = HIGH;                       // Button is pulled HIGH when not pressed
int lastButton2State = HIGH;                       // Button is pulled HIGH when not pressed
int lastButton3State = HIGH;
int DST = 0;                                       // Daylight Saving Time: DST=0(UTC-5), DST=1(UTC-4)
float brioff = 1;                                  // Brightness offset
int colorIndex = 1;                                // color change
int lastcolorIndex = 1;                            
int mode = 0;                                      // Defult mode: 0=clock, 1=Temperature, 2= Humidity
int lastmode = -1;
unsigned long lastHutime = 0;                      // Last time humidity changed
unsigned long lastTetime = 0;                      // Last time temperature changed
const unsigned long interval = 2000; 
int A = 0, B = 0, C = 0, D = 0, brt = 200;
int Te1 = 0, Te2=0, Te3 = 0;
int H1 = 0, H2 = 0, H3 = 0, H4 = 0; 

Preferences preferences;
RTC_DS3231 rtc;                                    // RTC
ClosedCube_OPT3001 opt3001;                        // Ambient sensor
ClosedCube_HDC1080 hdc1080;                        // Temp sensor
WiFiUDP udp;                                       // NTP setup
NTPClient ntp(udp, "pool.ntp.org", -18000, 60000); // Montreal
NeoPixelBus<NeoGrbFeature, NeoWs2812xMethod> strip(PixelCount, PixelPin);

RgbColor CLB;
RgbColor color[] = {                               // Define colors
  RgbColor(1, 0, 0),                               // Red
  RgbColor(0, 1, 0),                               // Green
  RgbColor(0, 0, 1),                               // Blue
  RgbColor(1, 0, 1),                               // Magenta
  RgbColor(1, 1, 0),                               // Yellow
  RgbColor(0, 1, 1),                               // Light blue
  RgbColor(1, 1, 1)                                // White
};

void setup() {
  Serial.begin(115200);
  Wire.begin();
  rtc.begin();
  pinMode(button1, INPUT_PULLUP);                  // Set button1 pin as input with pull-up
  pinMode(button2, INPUT_PULLUP);                  // Set button2 pin as input with pull-up
  pinMode(button3, INPUT_PULLUP);                  // Set button3 pin as input with pull-up

  initSensors();                                   // initialize hdc1080, opt3001, RTC
  preferences.begin("settings", false);
  DST = preferences.getInt("DST", 0);              // Default to 0 if no value is stored
  connectWiFi();                                   // Connect to WiFi and fetch NTPClient time
  syncRTC();                                       // Sync RTC with NTPClient time
  initDisplay();
  receive("mode", 0, 2, mode);
  receive("colorIndex", 0, 6, colorIndex);
  receive("brioff", 0.5, 10, brioff);
  receive("DST", 0, 1, DST);
}


void loop() {
  static unsigned long lastOffsetFetchTime1 = 0;
  static unsigned long lastOffsetFetchTime2 = 0;
  static unsigned long lastOffsetFetchTime3 = 0;
  unsigned long currentMillis1 = millis();
  unsigned long currentMillis2 = millis();
  unsigned long currentMillis3 = millis();
  unsigned long doublePress = 0; 
  const unsigned long delayPress = 4000;  
  static float lastbrioff = brioff;
  bool flagB = false;
  int button1State = digitalRead(button1);
  int button2State = digitalRead(button2);
  int button3State = digitalRead(button3); 

  static unsigned long lastsend = 0;
  unsigned long nowsend = millis();
  if (nowsend - lastsend > 10000) { 
    temp_hu_server ();
    lastsend = nowsend;
  }

  if (brioff != lastbrioff) {
    send("brioff", brioff);
    lastbrioff = brioff;
  }

//SWITCH 1
  if (lastButton1State == HIGH && button1State == LOW) {             
    flagB = true;
    colorIndex = (colorIndex + 1) % 7;
    send("colorIndex", colorIndex); 
    flagB = true; 
    doublePress = millis();
  }
  lastButton1State = button1State;

//SWITCH 2
  if (lastButton2State == HIGH && button2State == LOW) {
    flagB = true;
    mode = (mode + 1) % 3;
    send("mode",mode);
    flagB = true;
    doublePress = millis();
  }
  lastButton2State = button2State;

//SWITCH 3
  if (lastButton3State == HIGH && button3State == LOW) {
    flagB = true;
    DST = (DST + 1) % 2;
    send("DST", DST);
    preferences.putInt("DST", DST);
    if (WiFi.status() == WL_CONNECTED) {
      ntp.update();  
      syncRTC();
    }
  }
  lastButton3State = button3State;


// Fetch from server
  if (!flagB && currentMillis1 - lastOffsetFetchTime1 > 2000) { 
    if (millis() - doublePress > delayPress) {
      receive("colorIndex", 0, 6, colorIndex); 
      receive("mode",0, 2, mode);  
      lastOffsetFetchTime1 = currentMillis1;
    }
  }

  if (!flagB && currentMillis2 - lastOffsetFetchTime2 > 800) { 
    if (millis() - doublePress > delayPress) {
      receive("brioff", 0.5, 10, brioff);
      lastOffsetFetchTime2 = currentMillis2;
    }
  }
  
  if (!flagB && currentMillis3 - lastOffsetFetchTime3 > 30000) { 
    receive("DST", 0, 1, DST);
    lastOffsetFetchTime3 = currentMillis3;
  }



// Mode select
  if (mode == 0) {
    timeMode();
  }
  if (mode == 1) {
    tempMode();
  }
  if (mode == 2) {
    humidityMode();
  }
  lastmode = mode;
  lastcolorIndex = colorIndex;
  //delay(10); 
}


void timeMode() {
  static int lastA = -1, lastB = -1, lastC = -1, lastD = -1, lastBrt = -1;
  static float lastbrioff= -1;
  OPT3001 result = opt3001.readResult();
  int lux = result.lux;
  int brt = determine_brt(lux);
  updateTime();
  if (brt != lastBrt || brioff != lastbrioff || A != lastA || B != lastB || C != lastC || D != lastD || mode!= lastmode || lastcolorIndex != colorIndex) {
    clearDisplay();
    updateBrightness();
    updateTime();
    display(A, B, C, D, 2, CLB);
    lastBrt = brt; 
    lastbrioff= brioff;
    lastA = A;
    lastB = B;
    lastC = C;
    lastD = D;
  }
}

void tempMode() {
  static int lastTe1 = -1, lastTe2 = -1, lastTe3 = -1, lastBrt = -1;
  static float lastbrioff= -1;
  OPT3001 result = opt3001.readResult();
  int lux = result.lux;
  int brt = determine_brt(lux);

  if (millis() - lastTetime >= interval) {
    updateTemp();
    lastTetime = millis();
    if (Te1 != lastTe1 || Te2 != lastTe2 || Te3 != lastTe3) {
      lastTe1 = Te1;
      lastTe2 = Te2;
      lastTe3 = Te3;
      clearDisplay();
      display(Te1, Te2, Te3, 10, 1, CLB);
    }
  }
  if (brt != lastBrt || brioff != lastbrioff || mode != lastmode || lastcolorIndex != colorIndex) {
    updateBrightness();
    lastBrt = brt; 
    lastbrioff= brioff;
    clearDisplay();
    display(Te1, Te2, Te3, 10, 1, CLB);
  }
}

void humidityMode() {
  static int lastH1 = -1, lastH2 = -1, lastH3 = -1, lastH4 = -1, lastBrt = -1;
  static float lastbrioff= -1;
  OPT3001 result = opt3001.readResult();
  int lux = result.lux;
  int brt = determine_brt(lux);

  if (millis() - lastHutime >= interval) {
    updateHumidity ();
    lastHutime = millis();
    if (H1 != lastH1 || H2 != lastH2 || H3 != lastH3 || H4 != lastH4) {
      lastH1 = H1;
      lastH2 = H2;
      lastH3 = H3;
      lastH4 = H4;
      clearDisplay();
      display(H1, H2, H3, H4, 1, CLB);
    }
  }
  if (brt != lastBrt || brioff != lastbrioff || mode != lastmode || lastcolorIndex != colorIndex) {
    updateBrightness();
    lastBrt = brt; 
    lastbrioff= brioff;
    clearDisplay();
    display(H1, H2, H3, H4, 1, CLB);
  }
}

void send(String parameterName, int value) {
  if (WiFi.status() == WL_CONNECTED) {
    HTTPClient http;
    String url = String(serverUrl) + parameterName + ".php" + "?" + parameterName + "=" + String(value);
    http.begin(url);
    int httpResponseCode = http.GET();
    http.end();
  } 
}

void send(String parameterName, float value) {
  if (WiFi.status() == WL_CONNECTED) {
    HTTPClient http;
    String url = String(serverUrl) + parameterName + ".php" + "?" + parameterName + "=" + String(value, 2);
    http.begin(url);
    int httpResponseCode = http.GET();
    http.end();
  } 
}

void receive(String parameterName, int minVal, int maxVal, int &outputValue) {
  if (WiFi.status() == WL_CONNECTED) {
    HTTPClient http;
    String url = String(serverUrl) + parameterName + ".php";
    http.begin(url);
    int httpResponseCode = http.GET();
    if (httpResponseCode > 0) {
      String payload = http.getString();
      int receivedValue = payload.toInt();  
      if (receivedValue >= minVal && receivedValue <= maxVal) {
        outputValue = receivedValue;
      } 
    }
    http.end();
  } 
}

void receive(String parameterName, float minVal, float maxVal, float &outputValue) {
  if (WiFi.status() == WL_CONNECTED) {
    HTTPClient http;
    String url = String(serverUrl) + parameterName + ".php";
    http.begin(url);
    int httpResponseCode = http.GET();
    if (httpResponseCode > 0) {
      String payload = http.getString();
      float receivedValue = payload.toFloat();  
      if (receivedValue >= minVal && receivedValue <= maxVal) {
        outputValue = receivedValue;
      } 
    }
    http.end();
  } 
}

void connectWiFi() {
  WiFi.begin(ssid, password);

  int attempts = 0;
  while (WiFi.status() != WL_CONNECTED && attempts < 10) {
    delay(200);
    attempts++;
  }
  if (WiFi.status() == WL_CONNECTED) {
    ntp.begin();
    ntp.update();
  } 
}

void syncRTC() {
  if (WiFi.status() == WL_CONNECTED) {
    ntp.update();
    DateTime now = DateTime(ntp.getEpochTime());
    rtc.adjust(now);
  }
}


void temp_hu_server () {
  if (WiFi.status() == WL_CONNECTED) {
    HTTPClient http;
    String url = String(serverUrl) + "sensor_data.php";
    http.begin(url);
    float temperature = hdc1080.readTemperature();
    float humidity = hdc1080.readHumidity();

    String postData = "temperature=" + String(temperature) + "&humidity=" + String(humidity);
    http.addHeader("Content-Type", "application/x-www-form-urlencoded");
    int httpResponseCode = http.POST(postData);
    http.end();
  }
}
